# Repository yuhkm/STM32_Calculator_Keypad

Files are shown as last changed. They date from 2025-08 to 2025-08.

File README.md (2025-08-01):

# STM32_Calculator_Keypad
STM32 Based USB Keypad and Calculator Project  
<br>


## Overview
Development Period : 2024.08 ~ 2024.11
<br>
### HW
- MCU : STM32F401RET6  
- Displsy : ST7789 1.9" TFT LCD  
- Battery : Li-Po 500mAh 3.7V  
- Interface: USB (for keypad mode and charging)
- Switches: Cherry MX compatible mechanical switches  
  ( Kailh hot-swap sockets )
-  
-  
 
### SW
- Maximum expression length: 70 characters
- Calculator supported Operations  
  Basic arithmetic : +, -, ×, ÷  
  Parentheses : (), {}, []  
  Trigonometric functions : sin, cos, tan  
  Planned support for : asin, acos, atan, log, ln   
-  
-  

## Key Features
- Mode 0 : Calculator
- Mode 1 : USB Keypad  
<br>

| USB C | Power S/W | Mode S/W | Function | Power source |
|:-----:|:---:|:---:|---|---|
| 0 | 0 | X | Power off | - |
| 0 | 1 | 0 | Calculator mode | Battery |
| 0 | 1 | 1 | - | - |
| 1 | 0 | X | Power off | Battery charge |
| 1 | 1 | 0 | Calculator mode | USB + Battery charge |
| 1 | 1 | 1 | USB Keypad mode | USB + Battery charge |




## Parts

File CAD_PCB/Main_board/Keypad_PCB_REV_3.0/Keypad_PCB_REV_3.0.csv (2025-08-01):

Reference | Value | Datasheet | Footprint | Qty | DNP
C1,C3,C4 | 10uF(0603) | ~ | Capacitor_SMD:C_0603_1608Metric | 3
C2,C5,C9,C10,C11,C12,C13,C14 | 100nF(0603) | ~ | Capacitor_SMD:C_0603_1608Metric | 8
C6,C8 | 1uF(0603) | ~ | Capacitor_SMD:C_0603_1608Metric | 2
C7 | 4.7uF(0603) | ~ | Capacitor_SMD:C_0603_1608Metric | 1
C15,C16 | 18pF(0603) | ~ | Capacitor_SMD:C_0603_1608Metric | 2
C17,C18 | 15pF(0603) | ~ | Capacitor_SMD:C_0603_1608Metric | 2
C19 | NU(0603) | ~ | Capacitor_SMD:C_0603_1608Metric_Pad1.08x0.95mm_HandSolder | 1
D1,D2,D3,D4,D5,D6,D7,D8,D9,D10,D11,D12,D13,D14,D15,D16,D17,D18,D19,D20,D21,D22 | 1N4148 | https://assets.nexperia.com/documents/data-sheet/1N4148_1N4448.pdf | Diode_THT:D_DO-35_SOD27_P7.62mm_Horizontal | 22
J1 | USB_C_Receptacle_USB2.0_16P | https://www.usb.org/sites/default/files/documents/usb_type-c.zip | Connector_USB:USB_C_Receptacle_G-Switch_GT-USB-7010ASV | 1
J2 | Conn_01x02_Socket | ~ | Connector_Molex:Molex_SPOX_5267-02A_1x02_P2.50mm_Vertical | 1
J4 | Conn_01x04_Pin | ~ | Connector_PinHeader_2.54mm:PinHeader_1x04_P2.54mm_Horizontal | 1
J5 | Conn_01x08_Pin | ~ | Connector_PinHeader_2.54mm:PinHeader_1x08_P2.54mm_Horizontal | 1
L1 | 2.2uH | ~ | Inductor_SMD:L_Bourns_SRP7028A_7.3x6.6mm | 1
LED1,LED2 | LED | ~ | LED_SMD:LED_0603_1608Metric | 2
MX1,MX2,MX3,MX4,MX5,MX6,MX7,MX8,MX9,MX10,MX11,MX12,MX13,MX14,MX15,MX16,MX17,MX18,MX19,MX20,MX21,MX22 | MX_SW_HS | ~ | PCM_marbastlib-mx:SW_MX_HS_CPG151101S11_1u | 22
Q1 | AO3401A | http://www.aosmd.com/pdfs/datasheet/AO3401A.pdf | Package_TO_SOT_SMD:SOT-23 | 1
R1,R2 | 5.1kR(0603) | ~ | Resistor_SMD:R_0603_1608Metric | 2
R3,R7,R8,R9,R10,R11,R16 | 10kR(0603) | ~ | Resistor_SMD:R_0603_1608Metric | 7
R4 | 100R(0603) | ~ | Resistor_SMD:R_0603_1608Metric | 1
R5,R6 | 22R(0603) | ~ | Resistor_SMD:R_0603_1608Metric | 2
R12,R13 | 1kR(0603) | ~ | Resistor_SMD:R_0603_1608Metric | 2
R14 | 30kR(0603) | ~ | Resistor_SMD:R_0603_1608Metric | 1
R15 | 7.5kR(0603) | ~ | Resistor_SMD:R_0603_1608Metric | 1
SD1 | SS14 | https://www.vishay.com/docs/88746/ss12.pdf | Diode_SMD:D_SMA | 1
ST9,ST19,ST20 | MX_stab |  | PCM_marbastlib-mx:STAB_MX_P_2u | 3
SW1,SW2 | SK-12D02-VG7 | https://datasheet.lcsc.com/szlcsc/Korean-Hroparts-Elec-SK-12D02-VG7_C136721.pdf | SK-12D02-VG7:SK12D02VG7 | 2
SW3,SW4 | TS-1088-AR02016 | https://www.xunpudianzi.com/uploads/pdf/TS-1088-ARXXX.pdf | TS-1088-AR02016:TS1088AR02016 | 2
SW5 | RotaryEncoder_Switch_MP | ~ | Rotary_Encoder:RotaryEncoder_Alps_EC11E-Switch_Vertical_H20mm | 1
U1 | STM32F401RETx | https://www.st.com/resource/en/datasheet/stm32f401re.pdf | Package_QFP:LQFP-64_10x10mm_P0.5mm | 1
U2 | ~ |  | Lipo:TP4056_Module | 1
U3 | TPS63001 | http://www.ti.com/lit/ds/symlink/tps63000.pdf | Package_SON:Texas_DRC0010J_ThermalVias | 1
Y1 | X322525MOB4SI | https://datasheet.lcsc.com/szlcsc/Yangxing-Tech-X322525MOB4SI_C9006.pdf | 25Mhz:X322525MOB4SI | 1
Y2 | Q13FC1350000400 | https://datasheet.lcsc.com/szlcsc/1901081604_Seiko-Epson-Q13FC1350000400_C32346.pdf | 32.768khz:Q13FC1350000400 | 1

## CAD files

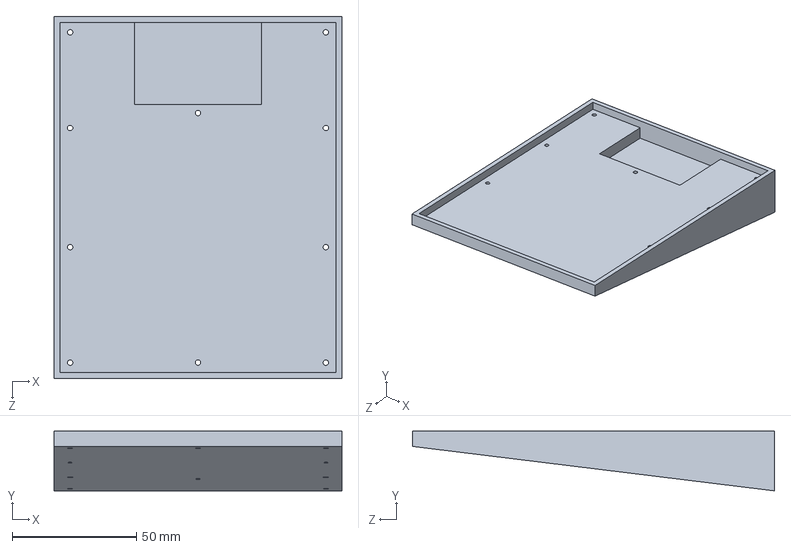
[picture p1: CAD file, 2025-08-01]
CAD_Case/bottom.SLDPRT
116.0 x 24.1 x 146.0 mm

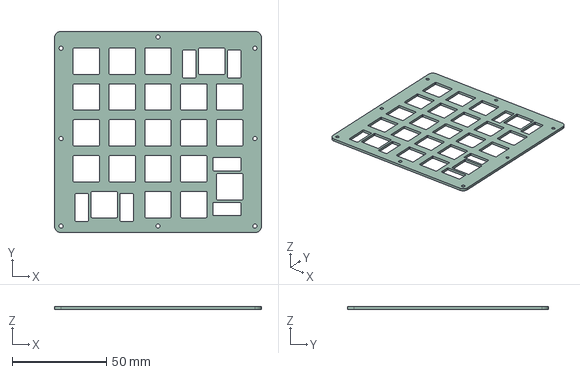
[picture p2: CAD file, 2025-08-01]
CAD_Case/Keypad_Top_REV_1_0.step
110.0 x 107.0 x 1.60 mm

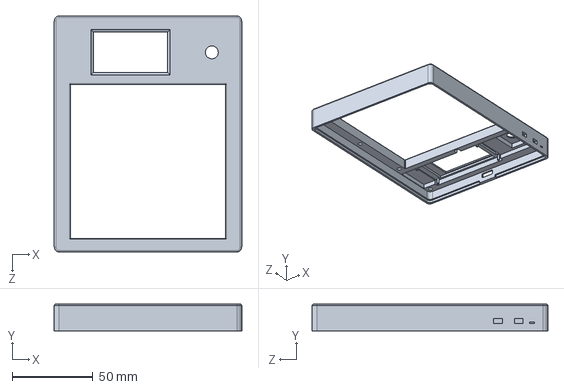
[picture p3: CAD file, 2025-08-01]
CAD_Case/top_case.SLDPRT
116.0 x 16.6 x 146.0 mm

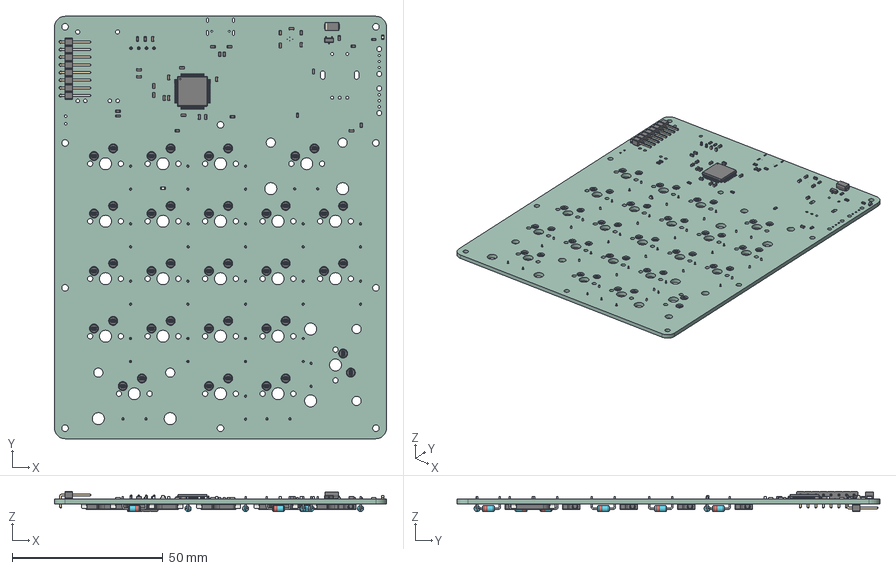
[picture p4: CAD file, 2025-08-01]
CAD_Case/Keypaad_Calculator_REV_3_1.step
110.0 x 140.0 x 6.78 mm
C_0603_1608Metric x 19
R_0603_1608Metric x 16
PinHeader_1x08_P254mm_Horizontal
SOT_23
LED_0603_1608Metric x 2
D_SMA
LQFP_64_10x10mm_P05mm
Kailh Hotswap v2 x 22
D_DO-35_SOD27_P7.62mm_Horizontal x 22
PinHeader_1x04_P254mm_Horizontal
_autosave-Keypaad_Calculator_REV_3_1_PCB

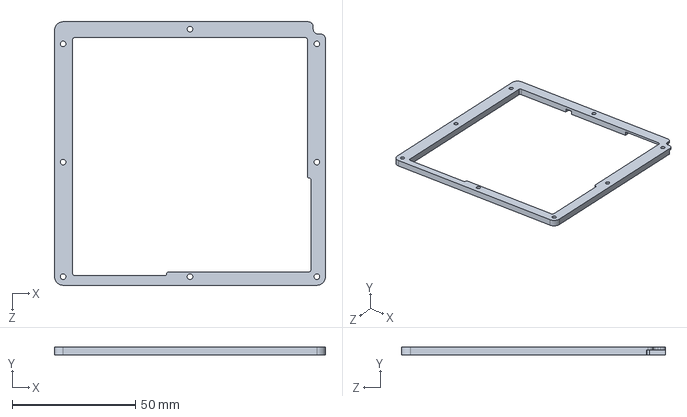
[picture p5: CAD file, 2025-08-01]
CAD_Case/mid.SLDPRT
110.0 x 3.40 x 107.0 mm

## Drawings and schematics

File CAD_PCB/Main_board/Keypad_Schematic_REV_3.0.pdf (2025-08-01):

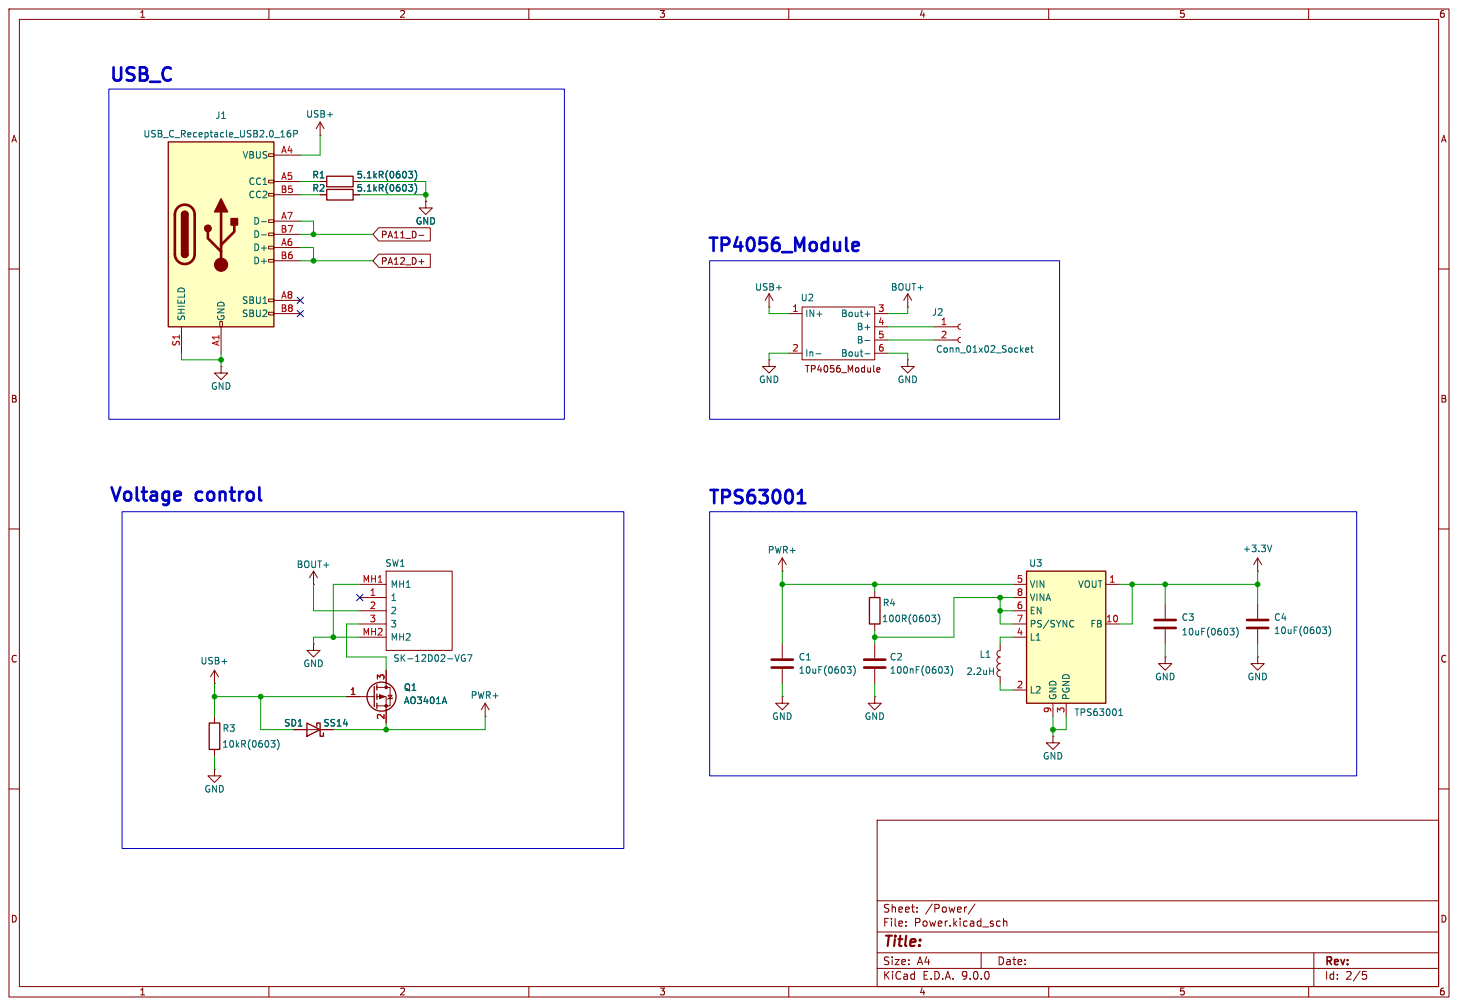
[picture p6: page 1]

Id: 2/5 Title: File: Power.kicad_sch Sheet: /Power/

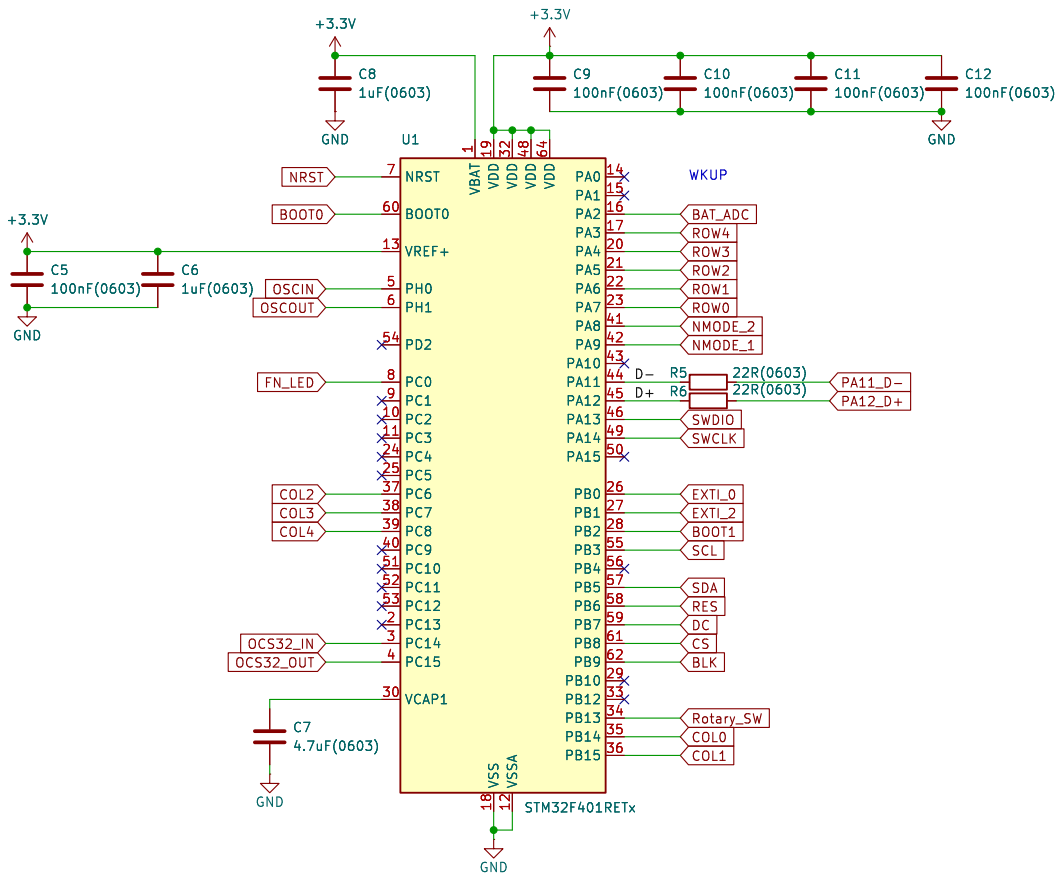
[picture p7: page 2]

Id: 3/5 Title: File: Stm32.kicad_sch Sheet: /Stm32/

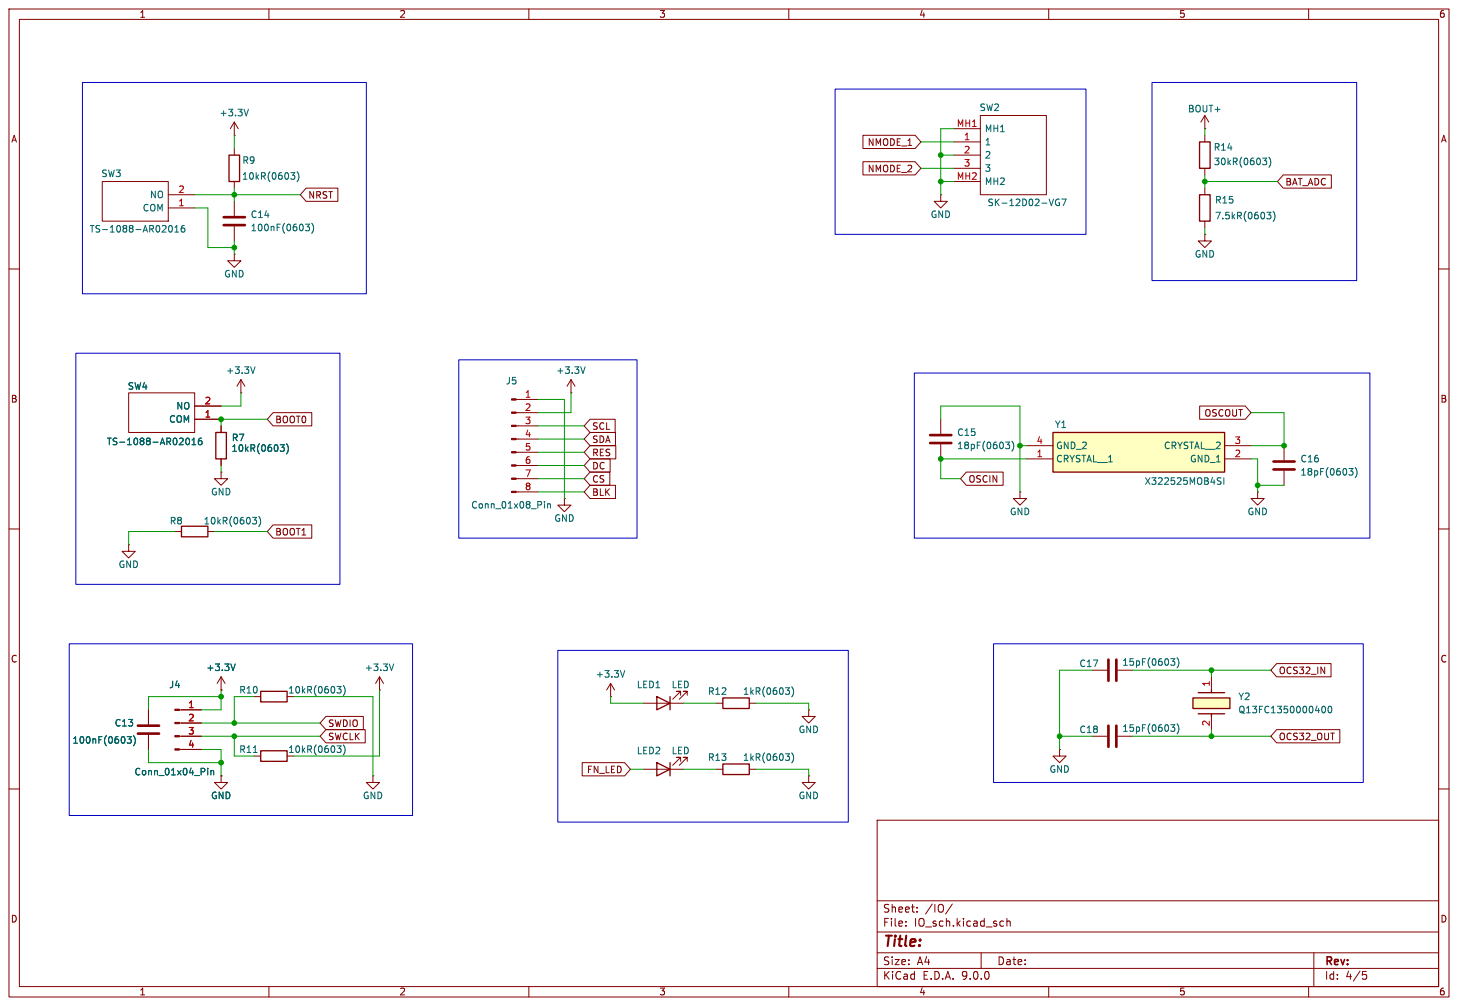
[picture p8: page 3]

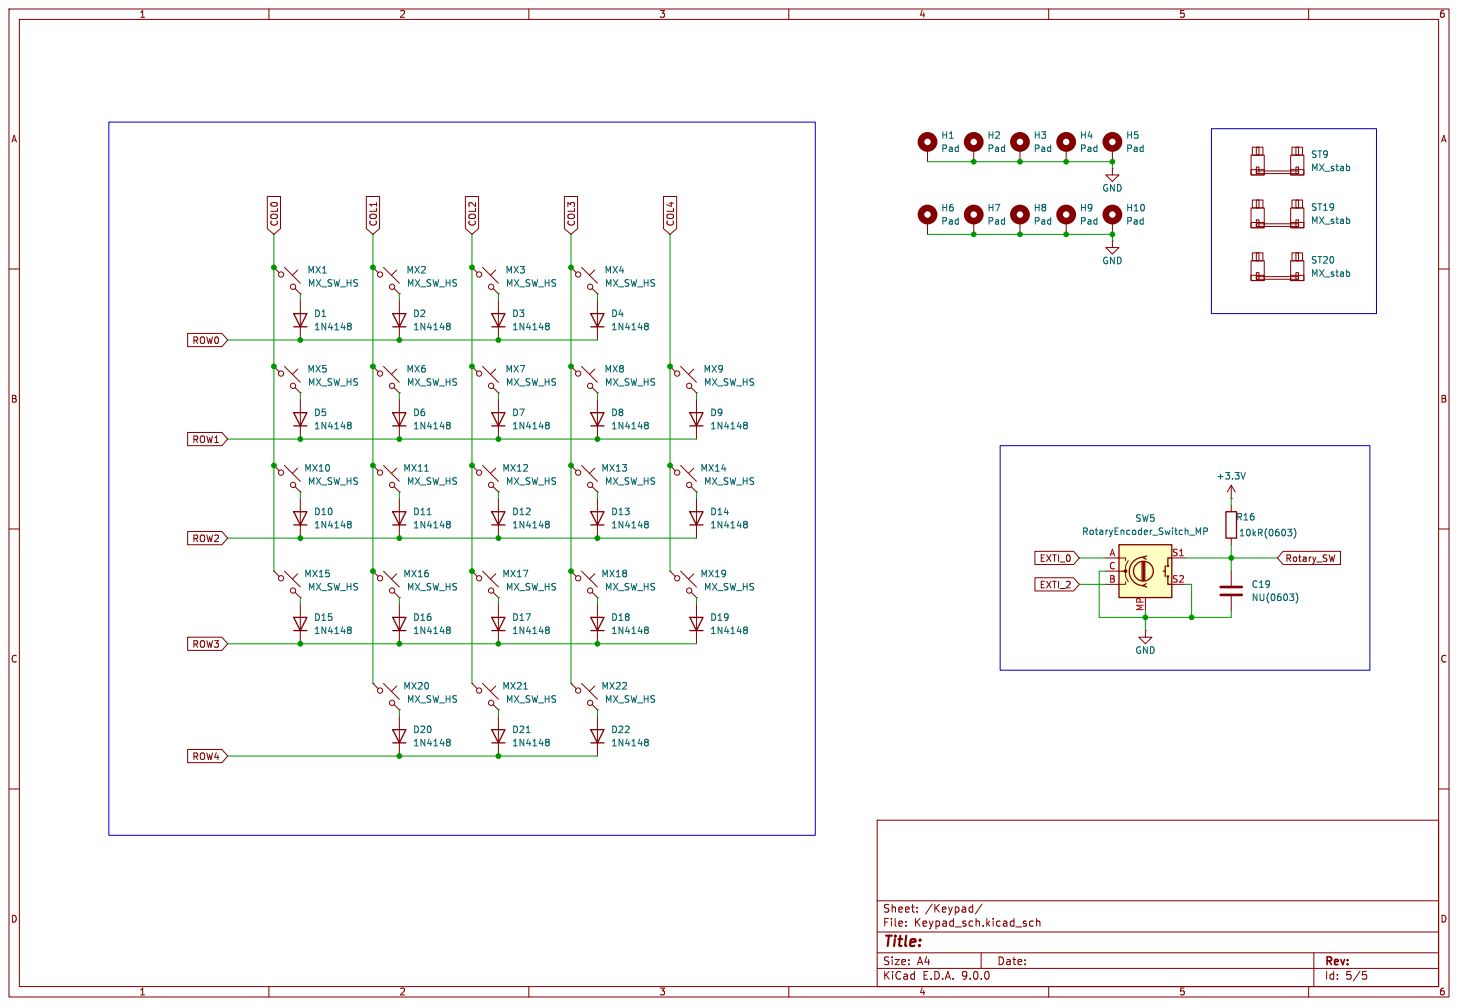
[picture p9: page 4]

Id: 5/5 Title: File: Keypad_sch.kicad_sch Sheet: /Keypad/ MX17 MX_SW_HS D7

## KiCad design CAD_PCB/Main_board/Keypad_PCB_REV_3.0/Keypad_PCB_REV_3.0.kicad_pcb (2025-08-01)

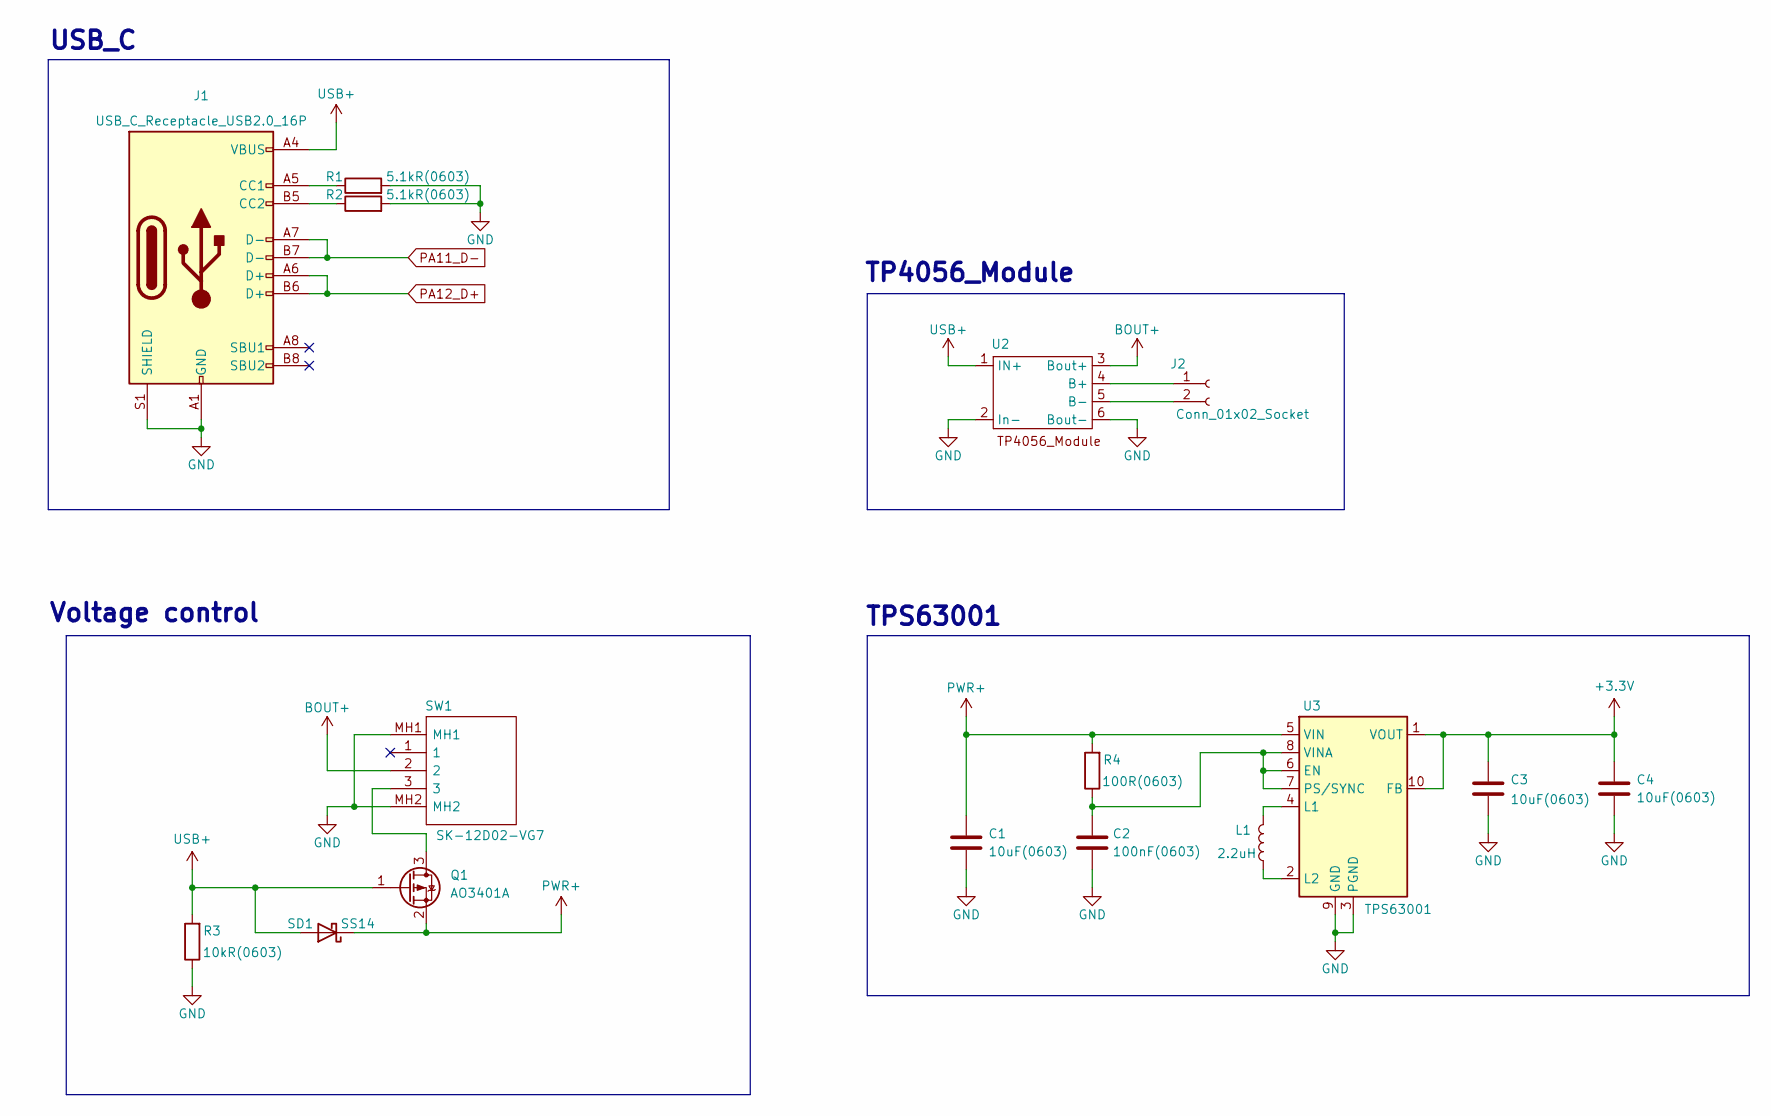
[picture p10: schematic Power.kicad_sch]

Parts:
C1, C3, C4: 10uF(0603); C_0603_1608Metric
C2: 100nF(0603); C_0603_1608Metric
J1: USB_C_Receptacle_USB2.0_16P; USB_C_Receptacle_G-Switch_GT-USB-7010ASV
J2: Conn_01x02_Socket; Molex_SPOX_5267-02A_1x02_P2.50mm_Vertical
L1: 2.2uH; L_Bourns_SRP7028A_7.3x6.6mm
Q1: AO3401A; SOT-23
R1, R2: 5.1kR(0603); R_0603_1608Metric
R3: 10kR(0603); R_0603_1608Metric
R4: 100R(0603); R_0603_1608Metric
SD1: SS14; D_SMA
SW1: SK-12D02-VG7; SK12D02VG7; Manufacturer_Part_Number SK-12D02-VG7
U2: TP4056_Module
U3: TPS63001; Texas_DRC0010J_ThermalVias

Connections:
+3.3V: C3.1, C4.1, U3.1 (VOUT), U3.10 (FB); also elsewhere on the board
BOUT+: SW1.2, U2.3 (Bout+); also elsewhere on the board
GND: C1.2, C2.2, C3.2, C4.2, J1.A1 (GND), J1.A12 (GND), J1.B1 (GND), J1.B12 (GND), J1.S1 (SHIELD), R1.2, R2.2, R3.1, SW1.MH1, SW1.MH2, U2.2 (In-), U2.6 (Bout-), U3.3 (PGND), U3.9 (GND), U3.11 (PGND); also elsewhere on the board
unnamed: J1.A5 (CC1), R1.1
unnamed: J1.B5 (CC2), R2.1
unnamed: J2.1, U2.4 (B+)
unnamed: J2.2, U2.5 (B-)
unnamed: Q1.3 (D), SW1.3
unnamed: C2.1, R4.1, U3.6 (EN), U3.7 (PS/SYNC), U3.8 (VINA)
unnamed: L1.2, U3.4 (L1)
unnamed: L1.1, U3.2 (L2)
PA11_D-: J1.A7 (D-), J1.B7 (D-); also elsewhere on the board
PA12_D+: J1.A6 (D+), J1.B6 (D+); also elsewhere on the board
PWR+: C1.1, Q1.2 (S), R4.2, SD1.1 (K), U3.5 (VIN)
USB+: J1.A4 (VBUS), J1.A9 (VBUS), J1.B4 (VBUS), J1.B9 (VBUS), Q1.1 (G), R3.2, SD1.2 (A), U2.1 (IN+)

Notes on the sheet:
TPS63001
USB_C
Voltage control
TP4056_Module

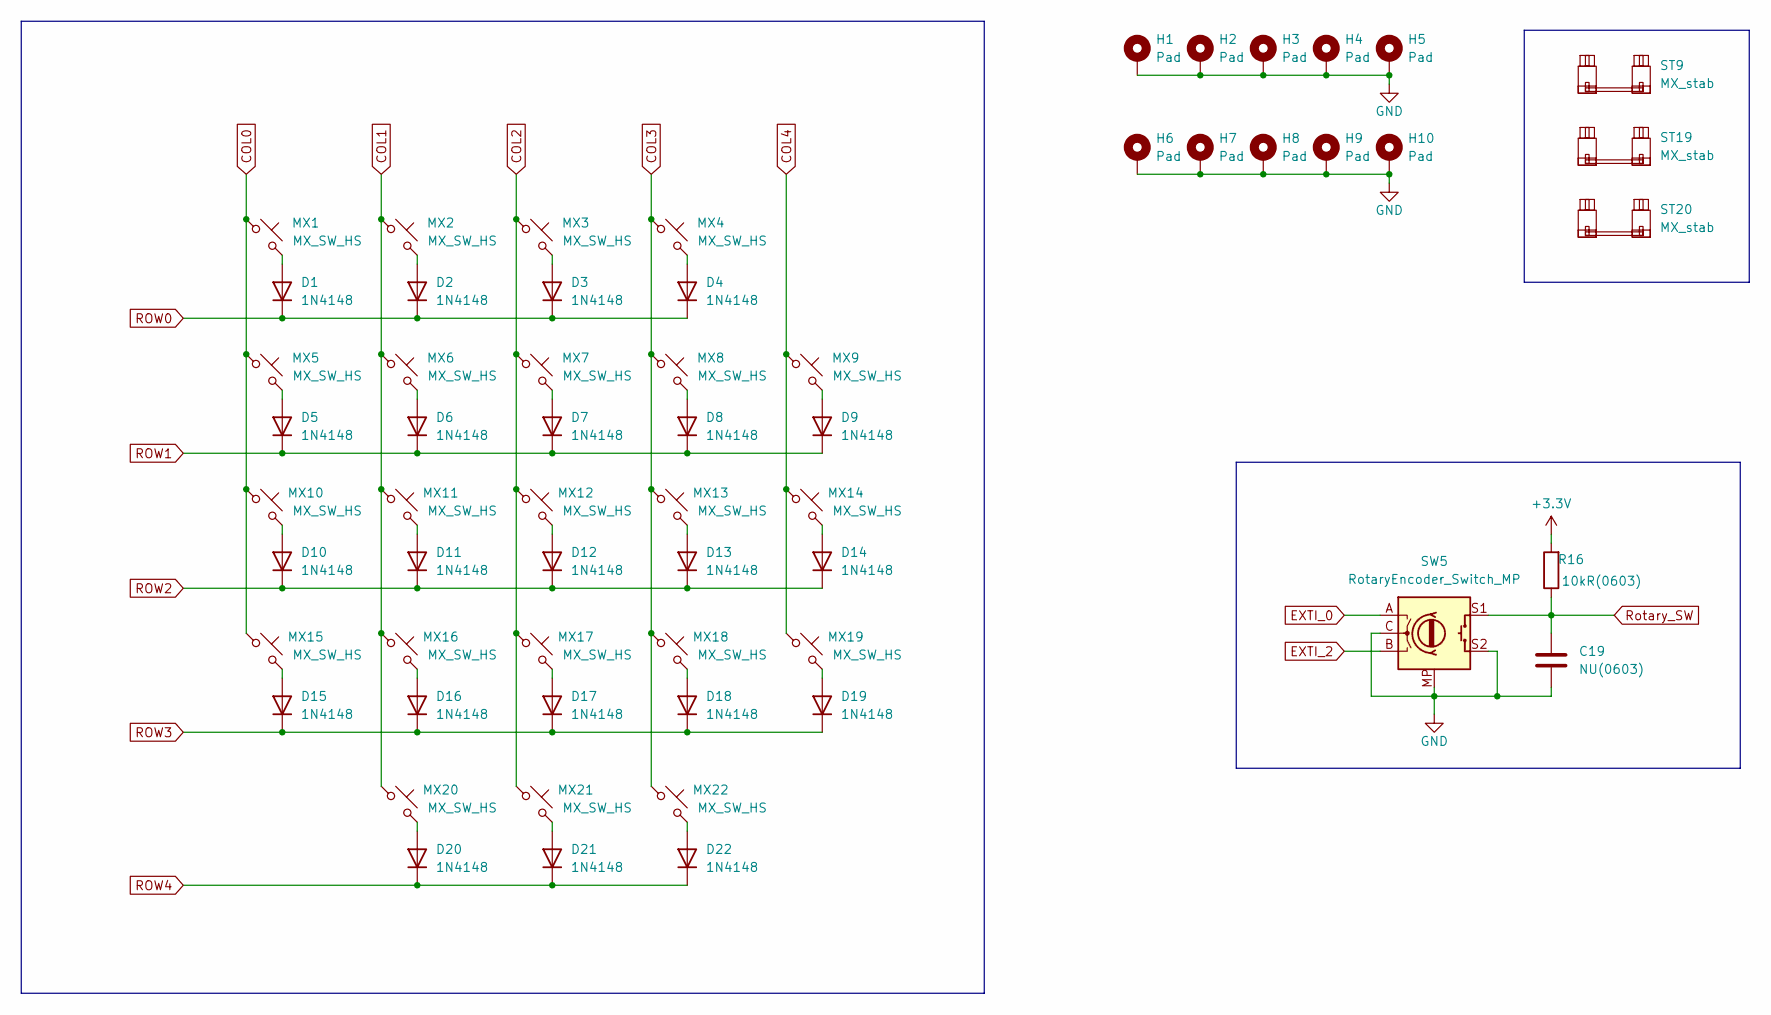
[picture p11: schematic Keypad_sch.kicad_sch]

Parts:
C19: NU(0603); C_0603_1608Metric_Pad1.08x0.95mm_HandSolder
D1, D2, D3, D4, D5, D6, D7, D8, D9, D10, D11, D12, D13, D14, D15, D16, D17, D18, D19, D20, D21, D22: 1N4148; D_DO-35_SOD27_P7.62mm_Horizontal
H1, H2, H3, H4, H5, H6, H7, H8, H9, H10: Pad; MountingHole_2.2mm_M2_DIN965_Pad_TopBottom
MX1, MX2, MX3, MX4, MX5, MX6, MX7, MX8, MX9, MX10, MX11, MX12, MX13, MX14, MX15, MX16, MX17, MX18, MX19, MX20, MX21, MX22: MX_SW_HS; SW_MX_HS_CPG151101S11_1u
R16: 10kR(0603); R_0603_1608Metric
ST9, ST19, ST20: MX_stab; STAB_MX_P_2u
SW5: RotaryEncoder_Switch_MP; RotaryEncoder_Alps_EC11E-Switch_Vertical_H20mm

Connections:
+3.3V: R16.2; also elsewhere on the board
COL0: MX1.1, MX5.1, MX10.1, MX15.1; also elsewhere on the board
COL1: MX2.1, MX6.1, MX11.1, MX16.1, MX20.1; also elsewhere on the board
COL2: MX3.1, MX7.1, MX12.1, MX17.1, MX21.1; also elsewhere on the board
COL3: MX4.1, MX8.1, MX13.1, MX18.1, MX22.1; also elsewhere on the board
COL4: MX9.1, MX14.1, MX19.1; also elsewhere on the board
EXTI_0: SW5.A; also elsewhere on the board
EXTI_2: SW5.B; also elsewhere on the board
GND: C19.2, H1.1, H2.1, H3.1, H4.1, H5.1, H6.1, H7.1, H8.1, H9.1, H10.1, SW5.C, SW5.MP, SW5.S2; also elsewhere on the board
unnamed: D1.2 (A), MX1.2
unnamed: D2.2 (A), MX2.2
unnamed: D3.2 (A), MX3.2
unnamed: D4.2 (A), MX4.2
unnamed: D5.2 (A), MX5.2
unnamed: D6.2 (A), MX6.2
unnamed: D7.2 (A), MX7.2
unnamed: D8.2 (A), MX8.2
unnamed: D9.2 (A), MX9.2
unnamed: D10.2 (A), MX10.2
unnamed: D11.2 (A), MX11.2
unnamed: D12.2 (A), MX12.2
unnamed: D13.2 (A), MX13.2
unnamed: D14.2 (A), MX14.2
unnamed: D15.2 (A), MX15.2
unnamed: D16.2 (A), MX16.2
unnamed: D17.2 (A), MX17.2
unnamed: D18.2 (A), MX18.2
unnamed: D19.2 (A), MX19.2
unnamed: D20.2 (A), MX20.2
unnamed: D21.2 (A), MX21.2
unnamed: D22.2 (A), MX22.2
ROW0: D1.1 (K), D2.1 (K), D3.1 (K), D4.1 (K); also elsewhere on the board
ROW1: D5.1 (K), D6.1 (K), D7.1 (K), D8.1 (K), D9.1 (K); also elsewhere on the board
ROW2: D10.1 (K), D11.1 (K), D12.1 (K), D13.1 (K), D14.1 (K); also elsewhere on the board
ROW3: D15.1 (K), D16.1 (K), D17.1 (K), D18.1 (K), D19.1 (K); also elsewhere on the board
ROW4: D20.1 (K), D21.1 (K), D22.1 (K); also elsewhere on the board
Rotary_SW: C19.1, R16.1, SW5.S1; also elsewhere on the board

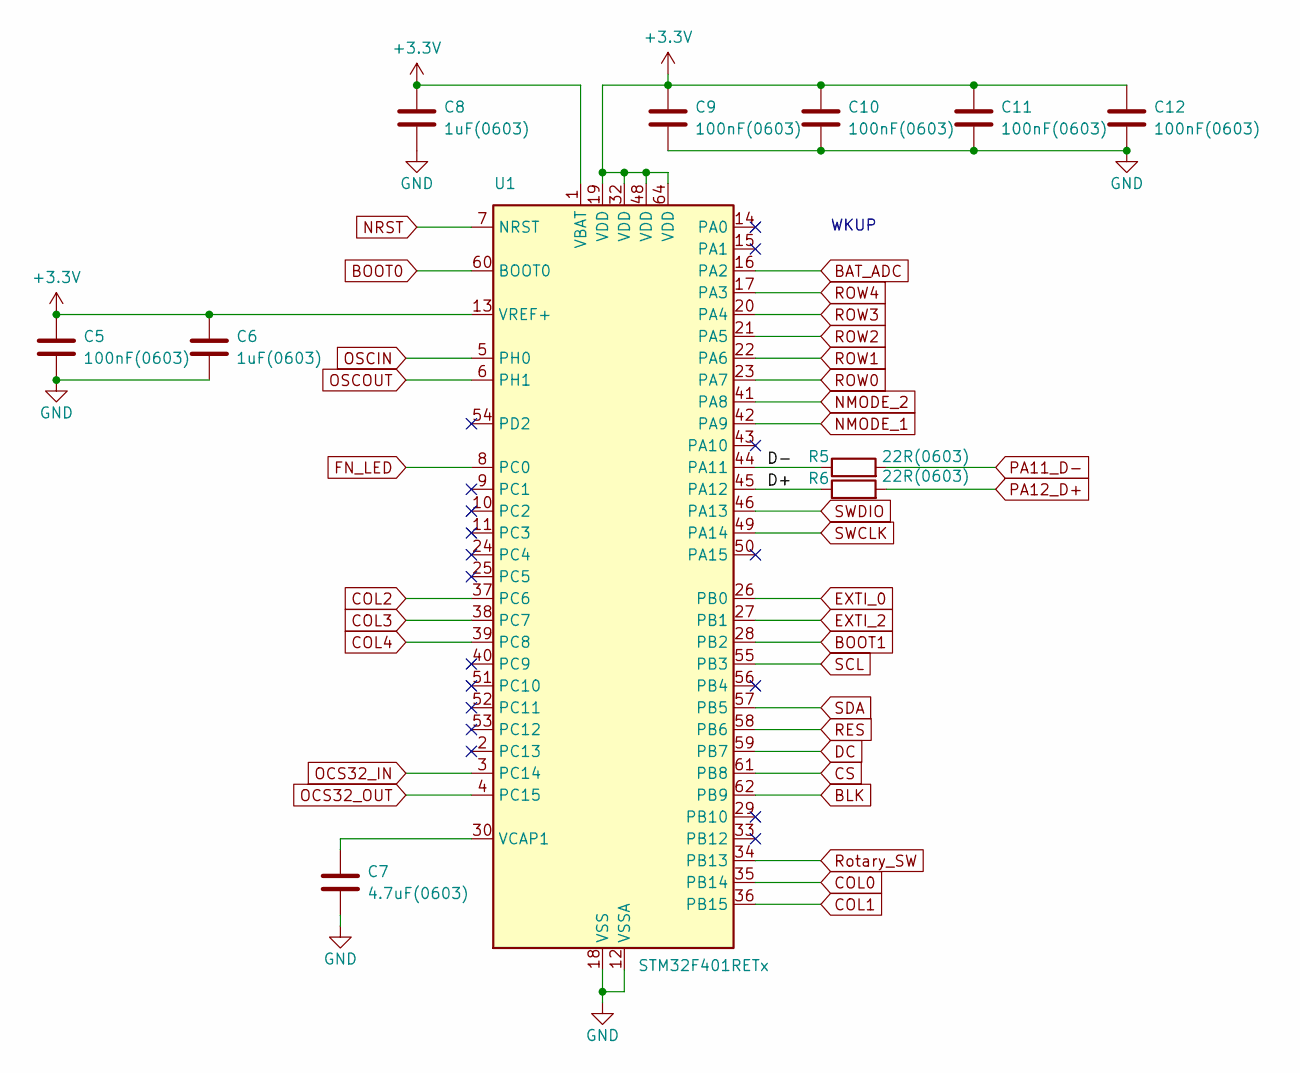
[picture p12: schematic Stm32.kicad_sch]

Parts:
C5, C9, C10, C11, C12: 100nF(0603); C_0603_1608Metric
C6, C8: 1uF(0603); C_0603_1608Metric
C7: 4.7uF(0603); C_0603_1608Metric
R5, R6: 22R(0603); R_0603_1608Metric
U1: STM32F401RETx; LQFP-64_10x10mm_P0.5mm

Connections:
+3.3V: C5.1, C6.1, C8.1, C9.1, C10.1, C11.1, C12.1, U1.1 (VBAT), U1.13 (VREF+), U1.19 (VDD), U1.32 (VDD), U1.48 (VDD), U1.64 (VDD); also elsewhere on the board
/Stm32/D+: R6.1, U1.45 (PA12)
/Stm32/D-: R5.1, U1.44 (PA11)
BAT_ADC: U1.16 (PA2); also elsewhere on the board
BLK: U1.62 (PB9); also elsewhere on the board
BOOT0: U1.60 (BOOT0); also elsewhere on the board
BOOT1: U1.28 (PB2); also elsewhere on the board
COL0: U1.35 (PB14); also elsewhere on the board
COL1: U1.36 (PB15); also elsewhere on the board
COL2: U1.37 (PC6); also elsewhere on the board
COL3: U1.38 (PC7); also elsewhere on the board
COL4: U1.39 (PC8); also elsewhere on the board
CS: U1.61 (PB8); also elsewhere on the board
DC: U1.59 (PB7); also elsewhere on the board
EXTI_0: U1.26 (PB0); also elsewhere on the board
EXTI_2: U1.27 (PB1); also elsewhere on the board
FN_LED: U1.8 (PC0); also elsewhere on the board
GND: C5.2, C6.2, C7.2, C8.2, C9.2, C10.2, C11.2, C12.2, U1.12 (VSSA), U1.18 (VSS), U1.31 (VSS), U1.47 (VSS), U1.63 (VSS); also elsewhere on the board
NMODE_1: U1.42 (PA9); also elsewhere on the board
NMODE_2: U1.41 (PA8); also elsewhere on the board
NRST: U1.7 (NRST); also elsewhere on the board
unnamed: C7.1, U1.30 (VCAP1)
OCS32_IN: U1.3 (PC14); also elsewhere on the board
OCS32_OUT: U1.4 (PC15); also elsewhere on the board
OSCIN: U1.5 (PH0); also elsewhere on the board
OSCOUT: U1.6 (PH1); also elsewhere on the board
PA11_D-: R5.2; also elsewhere on the board
PA12_D+: R6.2; also elsewhere on the board
RES: U1.58 (PB6); also elsewhere on the board
ROW0: U1.23 (PA7); also elsewhere on the board
ROW1: U1.22 (PA6); also elsewhere on the board
ROW2: U1.21 (PA5); also elsewhere on the board
ROW3: U1.20 (PA4); also elsewhere on the board
ROW4: U1.17 (PA3); also elsewhere on the board
Rotary_SW: U1.34 (PB13); also elsewhere on the board
SCL: U1.55 (PB3); also elsewhere on the board
SDA: U1.57 (PB5); also elsewhere on the board
SWCLK: U1.49 (PA14); also elsewhere on the board
SWDIO: U1.46 (PA13); also elsewhere on the board

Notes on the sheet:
WKUP

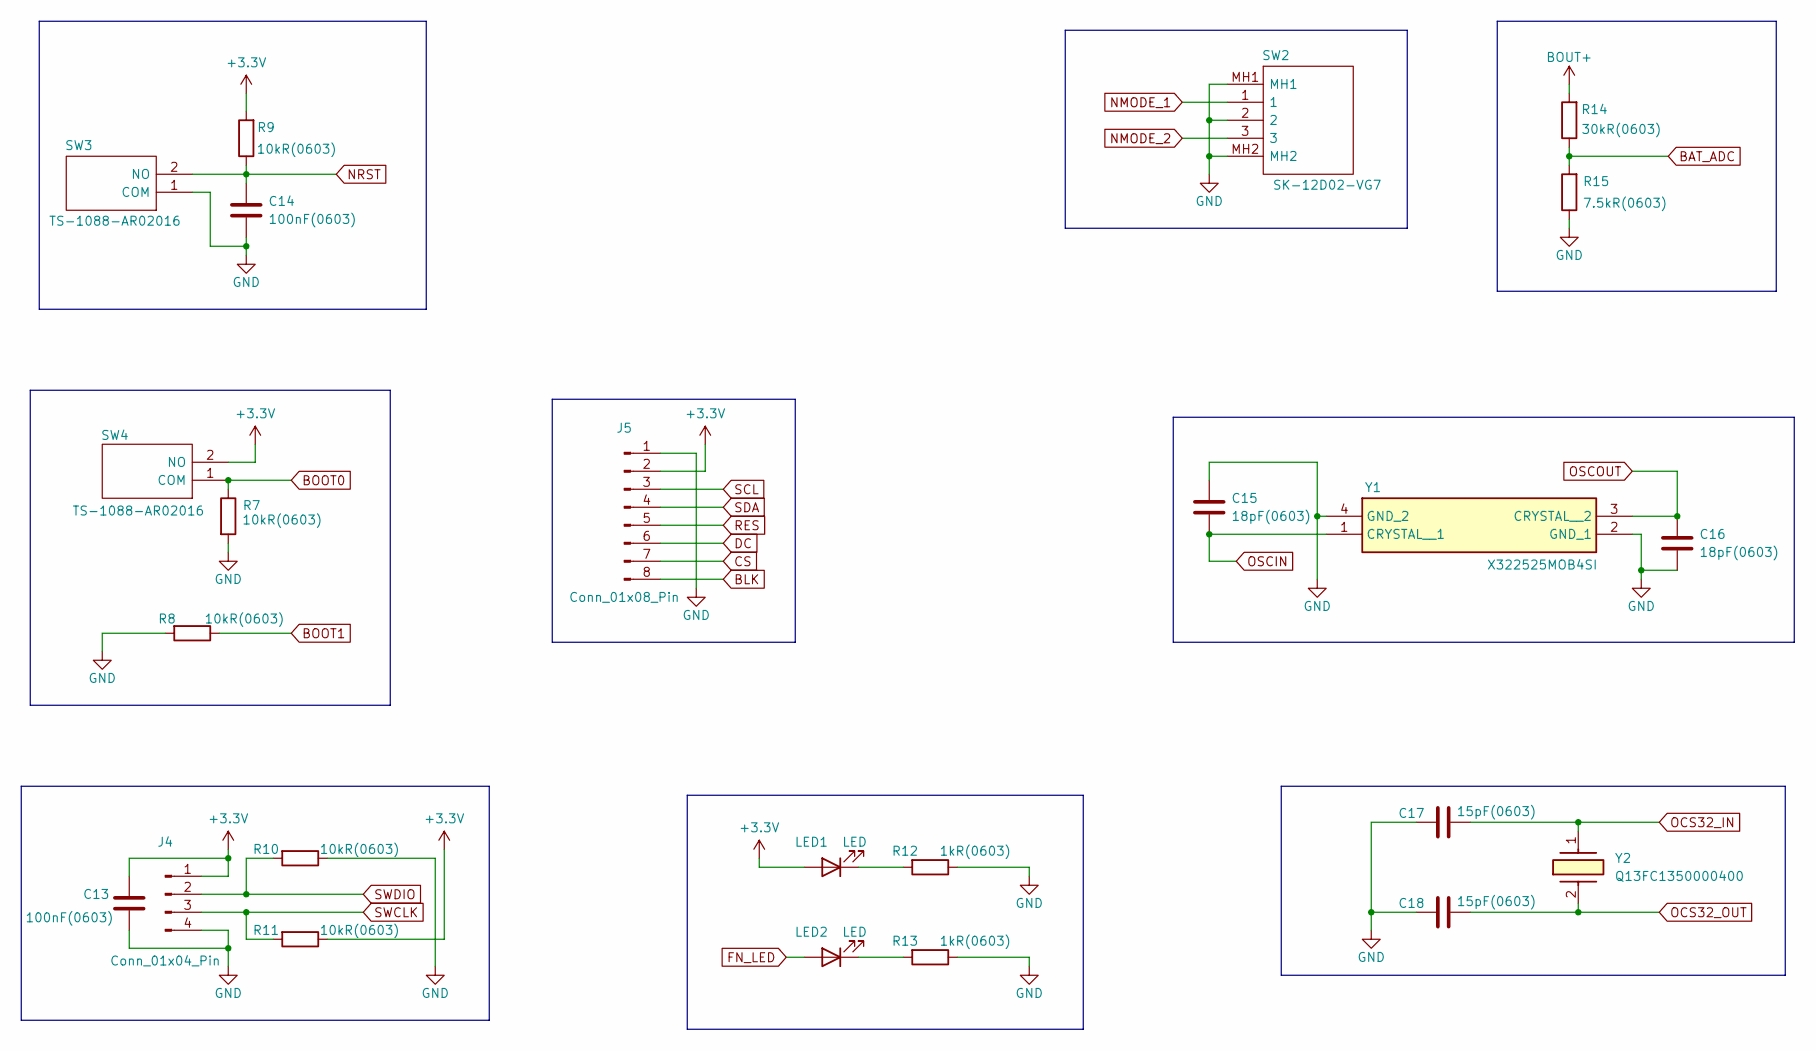
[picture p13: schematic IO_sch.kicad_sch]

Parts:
C13, C14: 100nF(0603); C_0603_1608Metric
C15, C16: 18pF(0603); C_0603_1608Metric
C17, C18: 15pF(0603); C_0603_1608Metric
J4: Conn_01x04_Pin; PinHeader_1x04_P2.54mm_Horizontal
J5: Conn_01x08_Pin; PinHeader_1x08_P2.54mm_Horizontal
LED1, LED2: LED; LED_0603_1608Metric
R7, R8, R9, R10, R11: 10kR(0603); R_0603_1608Metric
R12, R13: 1kR(0603); R_0603_1608Metric
R14: 30kR(0603); R_0603_1608Metric
R15: 7.5kR(0603); R_0603_1608Metric
SW2: SK-12D02-VG7; SK12D02VG7; Manufacturer_Part_Number SK-12D02-VG7
SW3, SW4: TS-1088-AR02016; TS1088AR02016; Manufacturer_Part_Number TS-1088-AR02016
Y1: X322525MOB4SI; Manufacturer_Part_Number X322525MOB4SI
Y2: Q13FC1350000400; Manufacturer_Part_Number Q13FC1350000400

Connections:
+3.3V: C13.1, J4.1, J5.2, LED1.2 (A), R9.2, R11.1, SW4.2 (NO); also elsewhere on the board
BAT_ADC: R14.1, R15.2; also elsewhere on the board
BLK: J5.8; also elsewhere on the board
BOOT0: R7.1, SW4.1 (COM); also elsewhere on the board
BOOT1: R8.1; also elsewhere on the board
BOUT+: R14.2; also elsewhere on the board
CS: J5.7; also elsewhere on the board
DC: J5.6; also elsewhere on the board
FN_LED: LED2.2 (A); also elsewhere on the board
GND: C13.2, C14.2, C15.1, C16.2, C17.1, C18.1, J4.4, J5.1, R7.2, R8.2, R10.1, R12.1, R13.1, R15.1, SW2.2, SW2.MH1, SW2.MH2, SW3.1 (COM), Y1.2 (GND_1), Y1.4 (GND_2); also elsewhere on the board
NMODE_1: SW2.1; also elsewhere on the board
NMODE_2: SW2.3; also elsewhere on the board
NRST: C14.1, R9.1, SW3.2 (NO); also elsewhere on the board
unnamed: LED1.1 (K), R12.2
unnamed: LED2.1 (K), R13.2
OCS32_IN: C17.2, Y2.1 (CRYSTAL); also elsewhere on the board
OCS32_OUT: C18.2, Y2.2 (CRYSTAL); also elsewhere on the board
OSCIN: C15.2, Y1.1 (CRYSTAL__1); also elsewhere on the board
OSCOUT: C16.1, Y1.3 (CRYSTAL__2); also elsewhere on the board
RES: J5.5; also elsewhere on the board
SCL: J5.3; also elsewhere on the board
SDA: J5.4; also elsewhere on the board
SWCLK: J4.3, R11.2; also elsewhere on the board
SWDIO: J4.2, R10.2; also elsewhere on the board

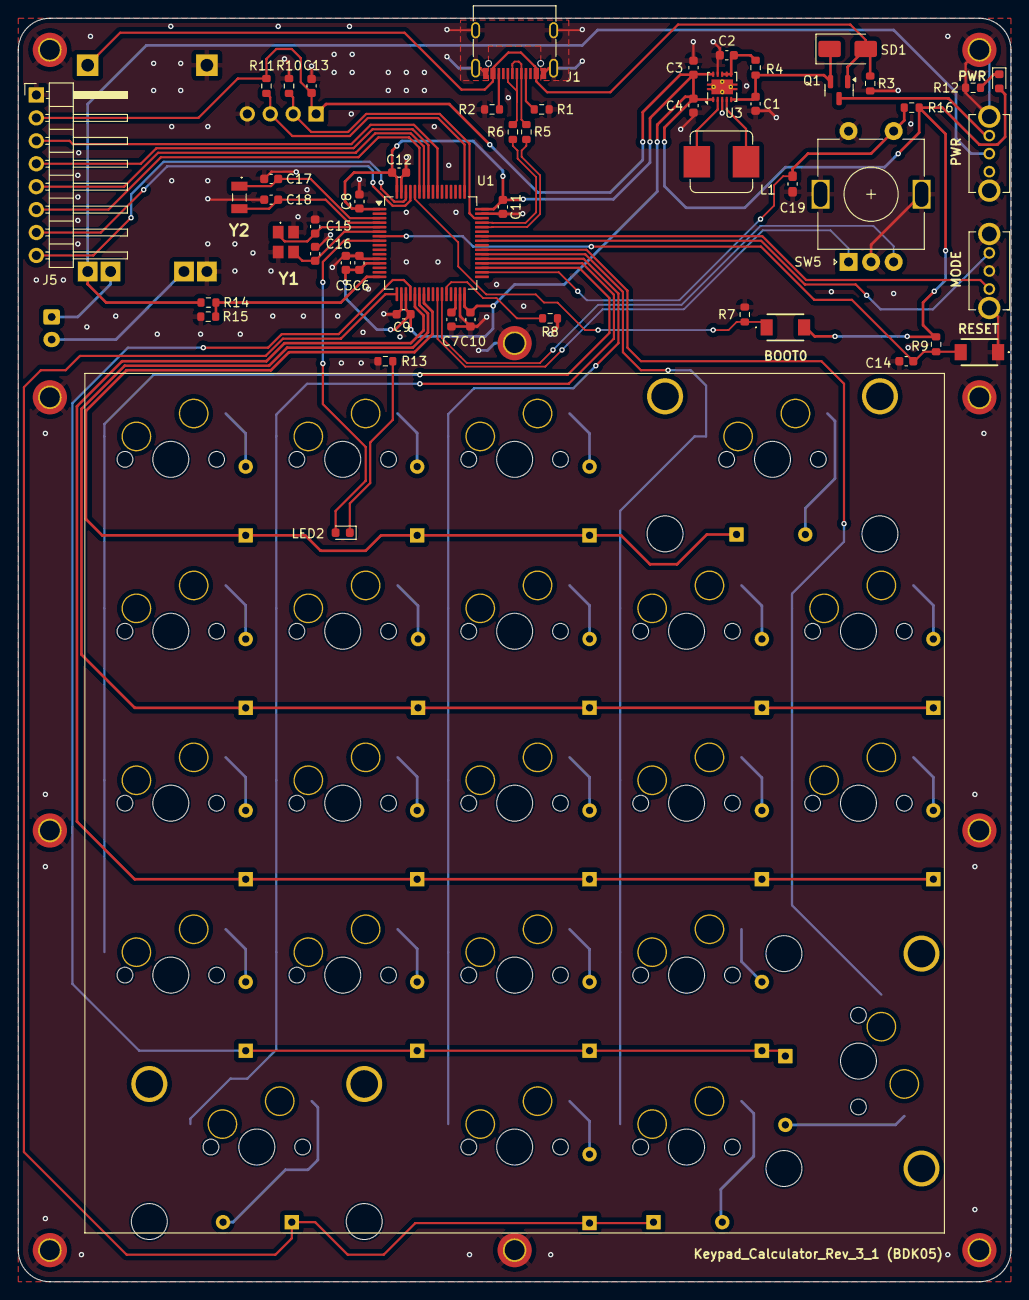
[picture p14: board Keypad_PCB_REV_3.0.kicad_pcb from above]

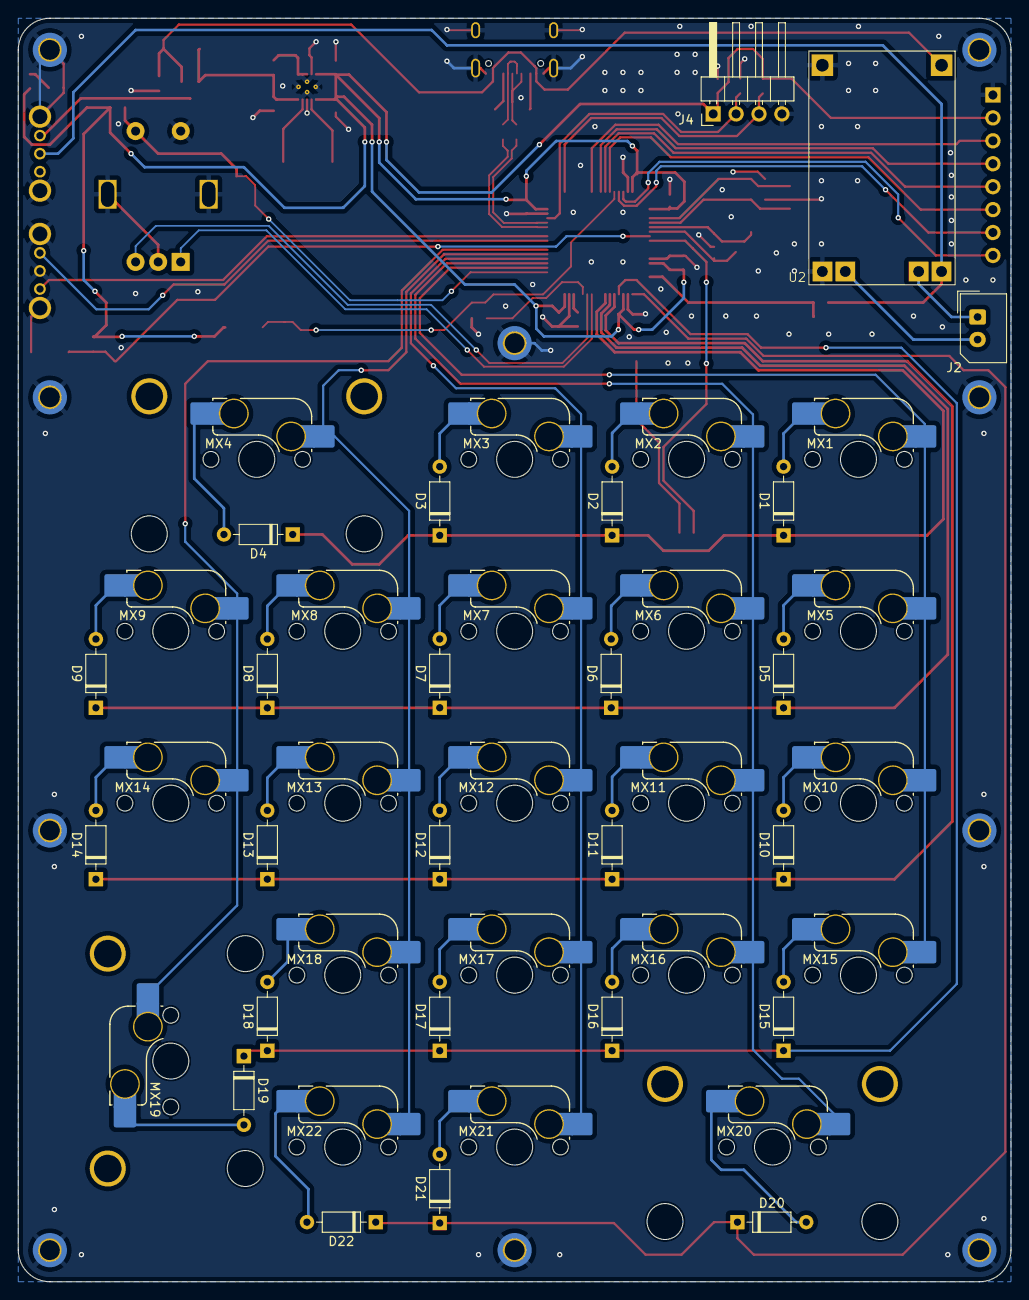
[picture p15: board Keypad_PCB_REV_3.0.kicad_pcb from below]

Board: 2 copper layers, 110.0 x 140.0 mm, 111 parts (47 on the bottom side), 74 nets.

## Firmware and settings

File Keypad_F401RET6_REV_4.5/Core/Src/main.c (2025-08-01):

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
/* Includes ------------------------------------------------------------------*/
#include "main.h"
#include "usb_device.h"

/* USER CODE BEGIN Includes */
#include "usbd_hid.h"
#include "keypadMode.h"
#include "readKeypad.h"
#include "hidKeypad.h"
#include "st7789.h"
#include "calculator.h"
#include "readBattery.h"


/* USER CODE END Includes */

/* USER CODE BEGIN PD */
//#define MAX_LCD_ROW_LENGTH 15
#define MAX_BUFFER_SIZE 74	//4 Line

/* USER CODE END PD */

ADC_HandleTypeDef hadc1;

SPI_HandleTypeDef hspi1;

TIM_HandleTypeDef htim2;

/* USER CODE BEGIN PV */
uint8_t mode1Key;
uint8_t nCursor = 0;
uint8_t prevMode = 0;
int fnMode = 0;
char mode2Key = 0;
char buffer[MAX_BUFFER_SIZE + 1] = "";
char caInput[MAX_BUFFER_SIZE + 1];


/* USER CODE END PV */

void SystemClock_Config(void);
static void MX_GPIO_Init(void);
static void MX_SPI1_Init(void);
static void MX_ADC1_Init(void);
static void MX_TIM2_Init(void);
/**
  * @brief  The application entry point.
  * @retval int
  */
int main(void)
{

  /* MCU Configuration--------------------------------------------------------*/

  /* Reset of all peripherals, Initializes the Flash interface and the Systick. */
  HAL_Init();

  /* Configure the system clock */
  SystemClock_Config();

  /* Initialize all configured peripherals */
  MX_GPIO_Init();
  MX_SPI1_Init();
  MX_USB_DEVICE_Init();
  MX_ADC1_Init();
  MX_TIM2_Init();
  /* USER CODE BEGIN 2 */
  ST7789_Init();
  HAL_TIM_Base_Start_IT(&htim2);


  /* USER CODE END 2 */

  /* Infinite loop */
  /* USER CODE BEGIN WHILE */
  while (1)
  {
	  int curMode = keypadMode_read();

	  if (curMode != prevMode)
	  {
		  if((prevMode == 2 )&& (curMode == 1))
		  {
			  HAL_GPIO_WritePin(BLK_PORT, BLK_PIN, GPIO_PIN_RESET);
		  }

		  ST7789_Fill_Color(BLACK);
		  prevMode = curMode;
		  buffer[0] = '\0';
		  nCursor = 0;
		  fnMode = 0;
		  printBattery();
	  }


	  if(fnMode == 0)
		  ST7789_WriteString(250, 5, "  ", Font_7x10, BLACK, BLACK);
	  else
		  ST7789_WriteString(250, 5, "Fn", Font_7x10, GREEN, BLACK);


	  if (curMode == 1)	//Mode1 (Keypad)
	  {
		  HAL_GPIO_WritePin(BLK_PORT, BLK_PIN, GPIO_PIN_RESET);

		  mode1Key = readKeypad_run ();

		  if (mode1Key != 0x01)
		  {
			  hidKeypad_sandKey(mode1Key);
		  }
	  }
	  else if (curMode == 2)	//Mode_2 (Calculator)
	  {
		  HAL_GPIO_WritePin(BLK_PORT, BLK_PIN, GPIO_PIN_SET);

		  ST7789_WriteString(10, 20, ">>", Font_16x26, WHITE, BLACK);

		  mode2Key = readKeypad_run();

		  if (mode2Key != 0xFF)
		  {
			  if (mode2Key == 'B') // Backspace
			  {
			      if (nCursor > 0)
			      {
			          nCursor--;

			          if (nCursor < 16)
			          {
			              ST7789_WriteString(50 + nCursor * 16, 20, " ", Font_16x26, BLACK, BLACK);
			          }
			          else if (16 <= nCursor && nCursor < 35)
			          {
			              ST7789_WriteString((nCursor - 16) * 16, 46, " ", Font_16x26, BLACK, BLACK);
			          }
			          else if (35 <= nCursor && nCursor < 54)
			          {
			              ST7789_WriteString((nCursor - 35) * 16, 72, " ", Font_16x26, BLACK, BLACK);
			          }
			          else if (54 <= nCursor && nCursor < 73)
			          {
			              ST7789_WriteString((nCursor - 54) * 16, 96, " ", Font_16x26, BLACK, BLACK);
			          }

			          buffer[nCursor] = '\0';
			      }
			  }
			  else if (mode2Key == 'E')		//Esc
			  {
				  ST7789_Fill_Color(BLACK);
				  HAL_Delay(100);
				  buffer[0] = '\0';
				  nCursor = 0;
				  printBattery();
			  }
			  else if (mode2Key == '=')
			  {
				  memcpy(caInput, buffer, sizeof(buffer));

				  calculator_run(caInput);

				  ST7789_WriteString(10, 130, "=", Font_16x26, WHITE, BLACK);
				  ST7789_WriteString(35, 130, caInput, Font_16x26, WHITE, BLACK);
			  }
			  else if ((fnMode == 0)&&((mode2Key == '/')||(mode2Key == '*')||(mode2Key == '-')))	//Fn=0 -> /, *, -
			  {
				  if (nCursor < MAX_BUFFER_SIZE - 1)
			      {
					  buffer[nCursor++] = mode2Key;
			          buffer[nCursor] = '\0';
			      }
			  }
			  else if ((fnMode == 1)&&((mode2Key == '/')||(mode2Key == '*')||(mode2Key == '-')))	//Fn=1 -> tri
			  {
				  if (nCursor < MAX_BUFFER_SIZE - 4)
				  {
					  if (mode2Key == '/')
				      {
						  buffer[nCursor++] = 's';
				          buffer[nCursor++] = 'i';
				          buffer[nCursor++] = 'n';
				      }
				      else if (mode2Key == '*')
				      {
				          buffer[nCursor++] = 'c';
				          buffer[nCursor++] = 'o';
				          buffer[nCursor++] = 's';
				      }
				      else if (mode2Key == '-')
				      {
				          buffer[nCursor++] = 't';
				          buffer[nCursor++] = 'a';
				          buffer[nCursor++] = 'n';
				      }
				      buffer[nCursor] = '\0';
				  }
			  }
			  else if (mode2Key == 'F')		//Fn
			  {
				  fnMode = !fnMode;
			  }
			  else if (mode2Key == 'R')		//Rev
			  {
			  }
			  else
			  {
				  if (nCursor < MAX_BUFFER_SIZE - 1)
			      {
					  buffer[nCursor++] = mode2Key;
			          buffer[nCursor] = '\0';
			      }
			  }

			  ST7789_WriteString(50, 20, buffer, Font_16x26, WHITE, BLACK);
		  }
	  }
	  else
	  {
		  HAL_GPIO_WritePin(BLK_PORT, BLK_PIN, GPIO_PIN_RESET);
	  }


    /* USER CODE END WHILE */

    /* USER CODE BEGIN 3 */
  }
  /* USER CODE END 3 */
}

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


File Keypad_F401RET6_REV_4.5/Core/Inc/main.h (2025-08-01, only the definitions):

#define Fn_LED_Pin GPIO_PIN_0
#define Fn_LED_GPIO_Port GPIOC
#define BAT_ADC_Pin GPIO_PIN_2
#define BAT_ADC_GPIO_Port GPIOA
#define COL4_Pin GPIO_PIN_3
#define COL4_GPIO_Port GPIOA
#define COL3_Pin GPIO_PIN_4
#define COL3_GPIO_Port GPIOA
#define COL2_Pin GPIO_PIN_5
#define COL2_GPIO_Port GPIOA
#define COL1_Pin GPIO_PIN_6
#define COL1_GPIO_Port GPIOA
#define COL0_Pin GPIO_PIN_7
#define COL0_GPIO_Port GPIOA
#define ROW0_Pin GPIO_PIN_14
#define ROW0_GPIO_Port GPIOB
#define ROW1_Pin GPIO_PIN_15
#define ROW1_GPIO_Port GPIOB
#define ROW2_Pin GPIO_PIN_6
#define ROW2_GPIO_Port GPIOC
#define ROW3_Pin GPIO_PIN_7
#define ROW3_GPIO_Port GPIOC
#define ROW4_Pin GPIO_PIN_8
#define ROW4_GPIO_Port GPIOC
#define NMODE_2_Pin GPIO_PIN_8
#define NMODE_2_GPIO_Port GPIOA
#define NMODE_1_Pin GPIO_PIN_9
#define NMODE_1_GPIO_Port GPIOA
#define RES_Pin GPIO_PIN_6
#define RES_GPIO_Port GPIOB
#define DC_Pin GPIO_PIN_7
#define DC_GPIO_Port GPIOB
#define CS_Pin GPIO_PIN_8
#define CS_GPIO_Port GPIOB
#define BLK_Pin GPIO_PIN_9
#define BLK_GPIO_Port GPIOB
#define ST7789_RST_GPIO_Port 	GPIOB
#define ST7789_RST_Pin       	GPIO_PIN_6
#define ST7789_DC_GPIO_Port  	GPIOB
#define ST7789_DC_Pin        	GPIO_PIN_7
#define ST7789_CS_GPIO_Port  	GPIOB
#define ST7789_CS_Pin        	GPIO_PIN_8
#define ST7789_BLK_GPIO_Port	GPIOB
#define ST7789_BLK_Pin        	GPIO_PIN_9

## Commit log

2025-08-01 Add cad files
    [IO_sch.kicad_sch, Keypaad_Calculator_REV_3_1.step, Keypad_PCB_REV_3.0.csv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]
2025-08-01 Add STM32 files0

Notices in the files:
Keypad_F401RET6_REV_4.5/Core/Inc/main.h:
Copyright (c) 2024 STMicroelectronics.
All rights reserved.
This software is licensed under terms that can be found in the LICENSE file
